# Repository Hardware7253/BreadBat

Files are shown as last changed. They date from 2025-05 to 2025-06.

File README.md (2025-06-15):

# BreadBat
A 3.3v breadbaord power supply that's powered by a single cell Li-Ion battery and uses USB-C for charging.
This design was made for prototyping portable devices on a breadboard.

I've had this designed manufactured and during testing I realised I forgot to consider the drop out voltage of the linear regulator. The battery charging and circuit protection seems to work fine, but the battery voltage isn't high enough for the LDO to reach a 3.3v output.



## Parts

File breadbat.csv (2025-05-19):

Reference | Value | Footprint | Qty | LCSC / JLC Part | Manufacturer | Part Number
BT1 | Battery_Cell | breadbat:JST_PH_B2B-PH-K_1x02_P2.00mm_Vertical | 1 | C131337 | JST | B2B-PH-K-S(LF)(SN)
C1,C2 | 10u | Capacitor_SMD:C_0603_1608Metric | 2 | C19702 | Samsung | CL10A106KP8NNNC
C3,C6 | 1u | Capacitor_SMD:C_0603_1608Metric | 2 | C15849 | Samsung | CL10A105KB8NNNC
C4,C5 | 22u | Capacitor_SMD:C_0805_2012Metric | 2 | C45783 | Samsung | CL21A226MAQNNNE
D1,D3 | D_TVS | Diode_SMD:D_SOD-323_HandSoldering | 2 | C5143684 | WPMtek(Wei Pan Microelectronics) | WPE0731D3
D2 | ORANGE | LED_SMD:LED_0603_1608Metric | 1 | C2287 | Kento | KT-0603Y
D4 | WHITE | LED_SMD:LED_0603_1608Metric | 1 | C2290 | Kento | KT-0603W
D5 | RED | LED_SMD:LED_0603_1608Metric | 1 | C2286 | Kento | KT-0603R
J1 | USB_C_Receptacle_PowerOnly_6P | Connector_USB:USB_C_Receptacle_HRO_TYPE-C-31-M-17 | 1 | C2927302 | YIYUAN | YTC-TC6S-231
J2,J3 | Conn_02x03_Odd_Even | Connector_PinHeader_2.54mm:PinHeader_2x03_P2.54mm_Vertical | 2 | C492420 | XFCN | PZ254V-12-6P
R1,R4,R7,R11 | 1k2 | Resistor_SMD:R_0603_1608Metric | 4 | C22765 | UNI-ROYAL | 0603WAF1201T5E
R2,R3 | 5k1 | Resistor_SMD:R_0603_1608Metric | 2 | C23186 | UNI-ROYAL | 0603WAF5101T5E
R5 | 68k | Resistor_SMD:R_0603_1608Metric | 1 | C23231 | UNI-ROYAL | 0603WAF6802T5E
R6 | 120k | Resistor_SMD:R_0603_1608Metric | 1 | C25808 | UNI-ROYAL | 0603WAF1203T5E
R8,R10 | 47k | Resistor_SMD:R_0603_1608Metric | 2 | C25819 | UNI-ROYAL | 0603WAF4702T5E
R9 | 3k3 | Resistor_SMD:R_0603_1608Metric | 1 | C22978 | UNI-ROYAL | 0603WAF3301T5E
TP1,TP2 | TestPoint | TestPoint:TestPoint_Pad_D1.5mm | 2
U1 | TP4056-42-ESOP8 | Package_SO:SOIC-8-1EP_3.9x4.9mm_P1.27mm_EP2.41x3.3mm_ThermalVias | 1 | C16581 | TOPPOWER | TP4056-42-ESOP8
U2 | AMS1117-3.3 | Package_TO_SOT_SMD:SOT-223-3_TabPin2 | 1 | C347222 | UMW | AMS1117-3.3
U3 | TPS259621 | Package_SO:SOIC-8-1EP_3.9x4.9mm_P1.27mm_EP2.41x3.3mm_ThermalVias | 1 | C2155774 | Texas Instruments | TPS259621DDAR

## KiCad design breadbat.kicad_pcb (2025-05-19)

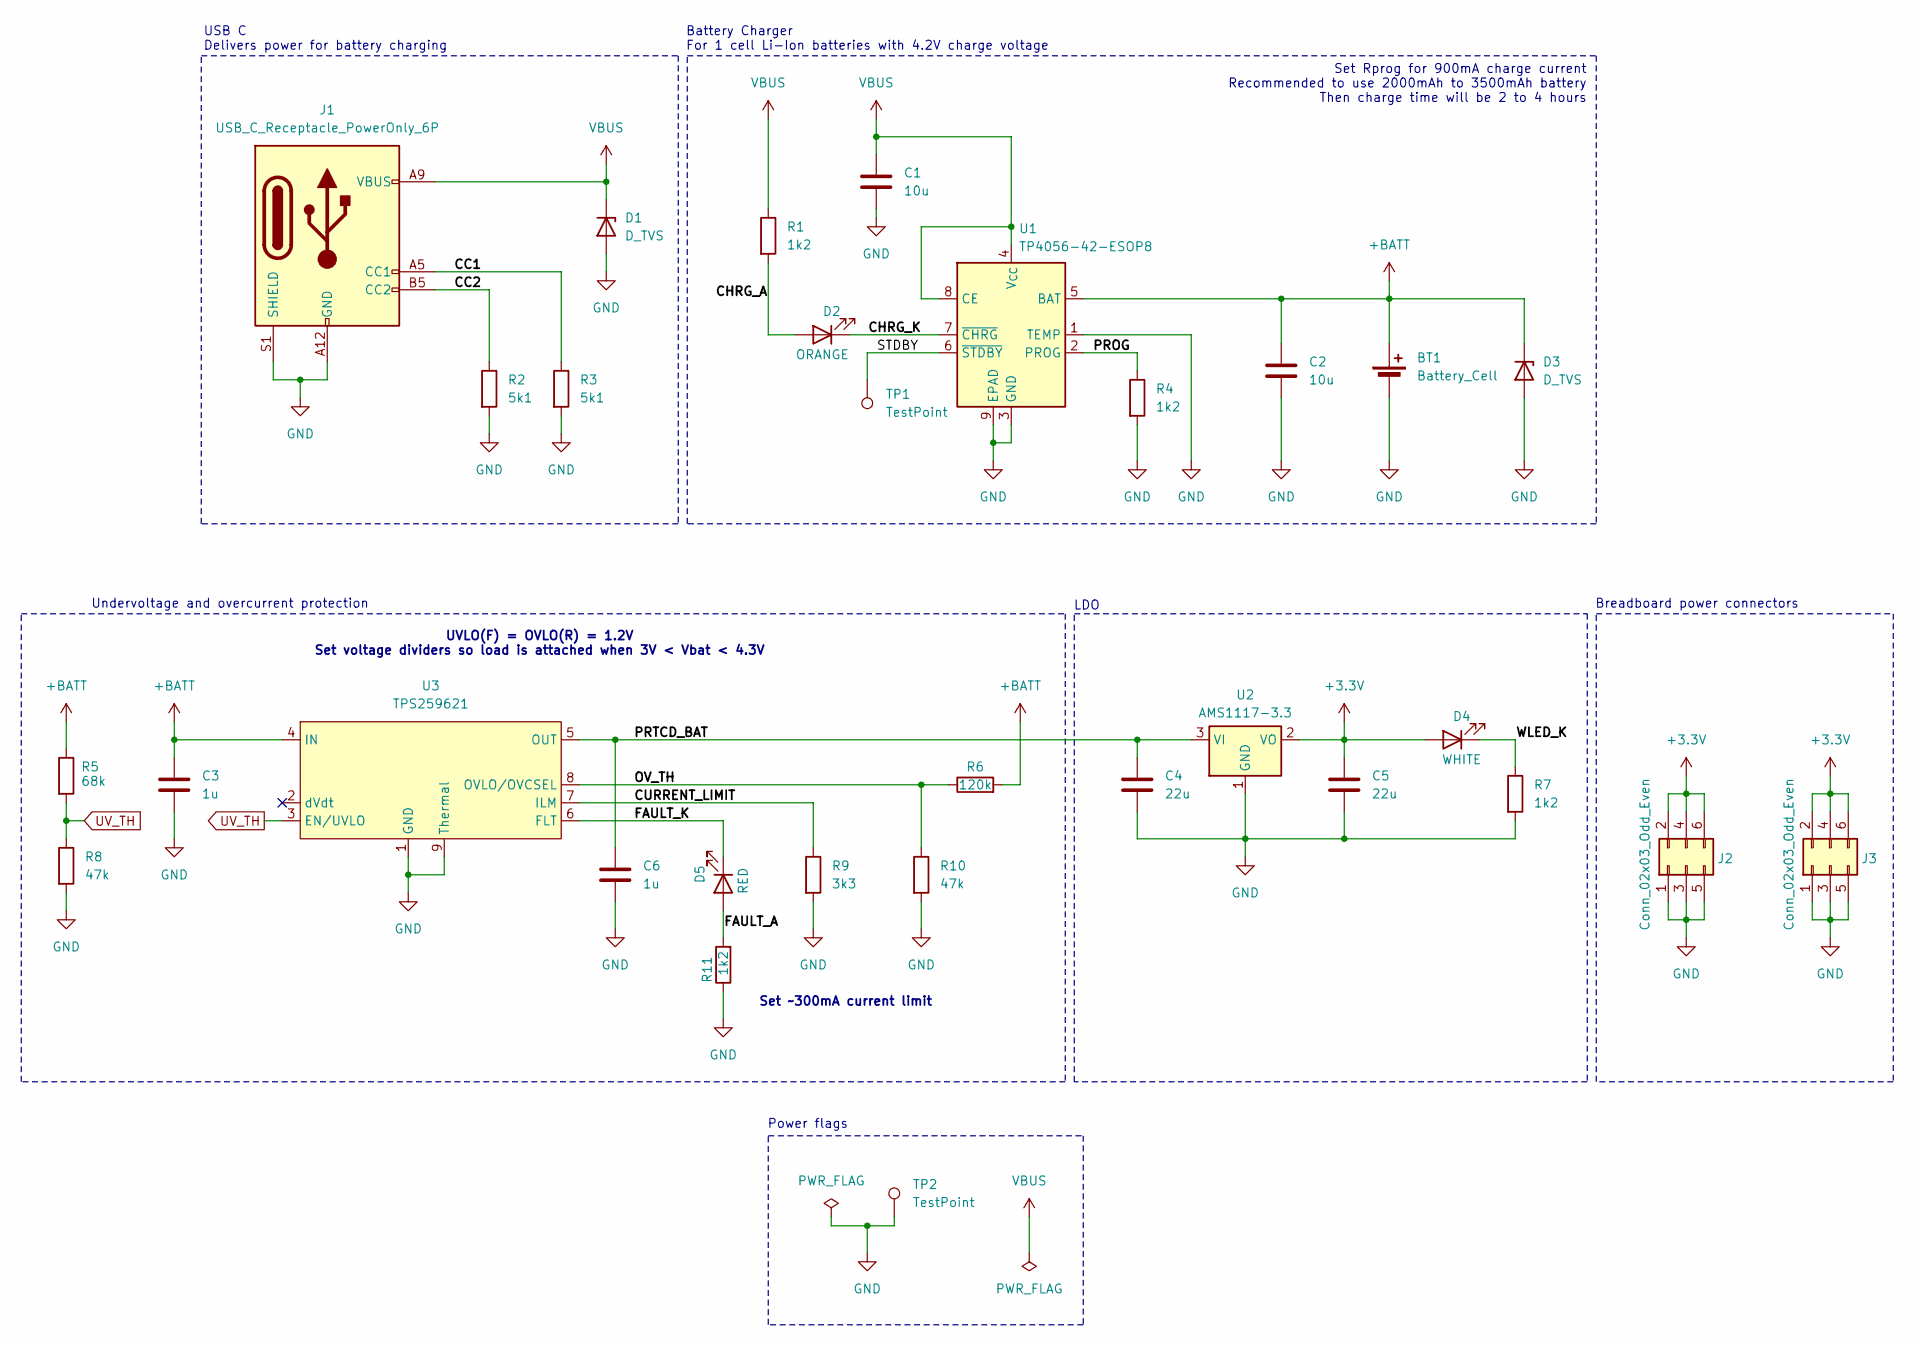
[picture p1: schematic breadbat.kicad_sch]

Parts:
BT1: Battery_Cell; JST_PH_B2B-PH-K_1x02_P2.00mm_Vertical; Part Number B2B-PH-K-S(LF)(SN); LCSC / JLC Part C131337
C1, C2: 10u; C_0603_1608Metric; Part Number CL10A106KP8NNNC; LCSC / JLC Part C19702
C3, C6: 1u; C_0603_1608Metric; Part Number CL10A105KB8NNNC; LCSC / JLC Part C15849
C4, C5: 22u; C_0805_2012Metric; Part Number CL21A226MAQNNNE; LCSC / JLC Part C45783
D1, D3: D_TVS; D_SOD-323_HandSoldering; Part Number WPE0731D3; LCSC / JLC Part C5143684
D2: ORANGE; LED_0603_1608Metric; Part Number KT-0603Y; LCSC / JLC Part C2287
D4: WHITE; LED_0603_1608Metric; Part Number KT-0603W; LCSC / JLC Part C2290
D5: RED; LED_0603_1608Metric; Part Number KT-0603R; LCSC / JLC Part C2286
J1: USB_C_Receptacle_PowerOnly_6P; USB_C_Receptacle_HRO_TYPE-C-31-M-17; Part Number YTC-TC6S-231; LCSC / JLC Part C2927302
J2, J3: Conn_02x03_Odd_Even; PinHeader_2x03_P2.54mm_Vertical; Part Number PZ254V-12-6P; LCSC / JLC Part C492420
R1, R4, R7, R11: 1k2; R_0603_1608Metric; Part Number 0603WAF1201T5E; LCSC / JLC Part C22765
R2, R3: 5k1; R_0603_1608Metric; Part Number 0603WAF5101T5E; LCSC / JLC Part C23186
R5: 68k; R_0603_1608Metric; Part Number 0603WAF6802T5E; LCSC / JLC Part C23231
R6: 120k; R_0603_1608Metric; Part Number 0603WAF1203T5E; LCSC / JLC Part C25808
R8, R10: 47k; R_0603_1608Metric; Part Number 0603WAF4702T5E; LCSC / JLC Part C25819
R9: 3k3; R_0603_1608Metric; Part Number 0603WAF3301T5E; LCSC / JLC Part C22978
TP1, TP2: TestPoint; TestPoint_Pad_D1.5mm
U1: TP4056-42-ESOP8; SOIC-8-1EP_3.9x4.9mm_P1.27mm_EP2.41x3.3mm_ThermalVias; Part Number TP4056-42-ESOP8; LCSC / JLC Part C16581
U2: AMS1117-3.3; SOT-223-3_TabPin2; Part Number AMS1117-3.3; LCSC / JLC Part C347222
U3: TPS259621; SOIC-8-1EP_3.9x4.9mm_P1.27mm_EP2.41x3.3mm_ThermalVias; Part Number TPS259621DDAR; LCSC / JLC Part C2155774

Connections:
+3.3V: C5.1, D4.2 (A), J2.2, J2.4, J2.6, J3.2, J3.4, J3.6, U2.2 (VO)
+BATT: BT1.1 (+), C2.1, C3.1, D3.1 (K), R5.1, R6.2, U1.5 (BAT), U3.4 (IN)
/CC1: J1.A5 (CC1), R3.1
/CC2: J1.B5 (CC2), R2.1
/CHRG_A: D2.2 (A), R1.2
/CHRG_K: D2.1 (K), U1.7 (~CHRG)
/CURRENT_LIMIT: R9.1, U3.7 (ILM)
/FAULT_A: D5.2 (A), R11.2
/FAULT_K: D5.1 (K), U3.6 (FLT)
/OV_TH: R6.1, R10.1, U3.8 (OVLO/OVCSEL)
/PROG: R4.1, U1.2 (PROG)
/PRTCD_BAT: C4.1, C6.1, U2.3 (VI), U3.5 (OUT)
/STDBY: TP1.1, U1.6 (~STDBY)
/WLED_K: D4.1 (K), R7.1
GND: BT1.2 (-), C1.2, C2.2, C3.2, C4.2, C5.2, C6.2, D1.2 (A), D3.2 (A), J1.A12 (GND), J1.B12 (GND), J1.S1 (SHIELD), J2.1, J2.3, J2.5, J3.1, J3.3, J3.5, R2.2, R3.2, R4.2, R7.2, R8.2, R9.2, R10.2, R11.1, TP2.1, U1.1 (TEMP), U1.3 (GND), U1.9 (EPAD), U2.1 (GND), U3.1 (GND), U3.9 (Thermal)
UV_TH: R5.2, R8.1, U3.3 (EN/UVLO)
VBUS: C1.1, D1.1 (K), J1.A9 (VBUS), J1.B9 (VBUS), R1.1, U1.4 (V_{CC}), U1.8 (CE)

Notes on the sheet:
LDO
Undervoltage and overcurrent protection
Power flags
UVLO(F) = OVLO(R) = 1.2V Set voltage dividers so load is attached when 3V < Vbat < 4.3V
Set ~300mA current limit
Breadboard power connectors
Set Rprog for 900mA charge current Recommended to use 2000mAh to 3500mAh battery Then charge time will be 2 to 4 hours
Battery Charger For 1 cell Li-Ion batteries with 4.2V charge voltage
USB C Delivers power for battery charging

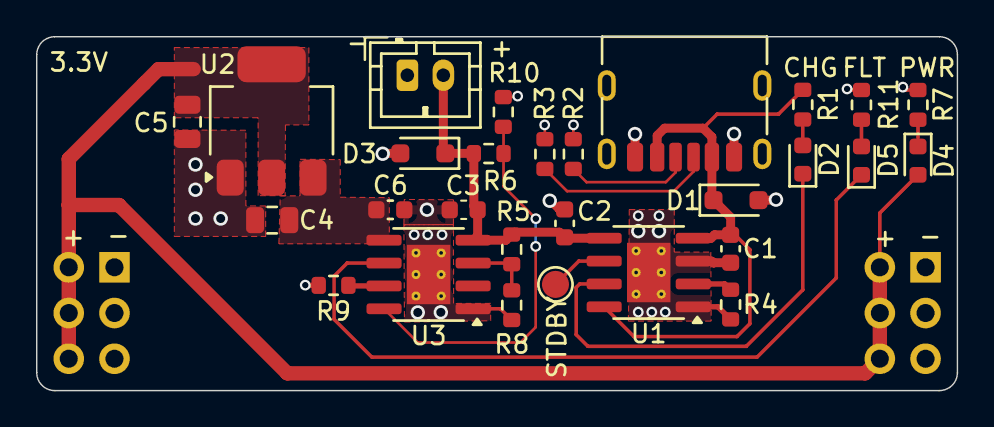
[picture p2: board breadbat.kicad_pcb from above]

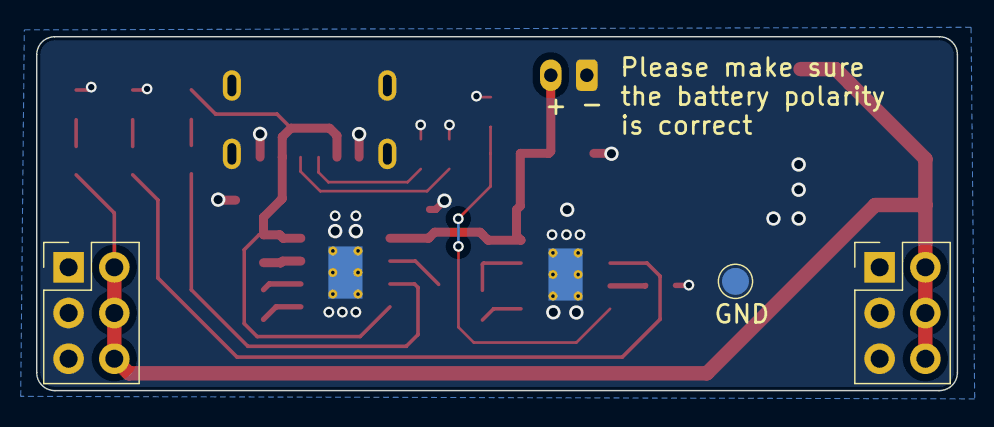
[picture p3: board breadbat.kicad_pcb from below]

Board: 2 copper layers, 51.2 x 19.7 mm, 31 parts (3 on the bottom side), 17 nets.
